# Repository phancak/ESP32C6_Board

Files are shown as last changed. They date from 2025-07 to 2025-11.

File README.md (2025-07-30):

# ESP32-C6 Expansion Board

## Overview

This project features a modular expansion board based on the **ESP32-C6** microcontroller, designed to showcase advanced wireless connectivity and interface flexibility for proof-of-concept embedded systems. The board includes **Wi-Fi 6**, **Bluetooth 5**, and **802.15.4 (Thread/Zigbee)** support, making it suitable for modern IoT applications. In addition to its wireless capabilities, the board exposes key communication interfaces like **QSPI**, **SPI**, **I2C**, and **UART**, enabling it to serve as a powerful, plug-and-play module in larger prototype systems.

## Features

- **ESP32-C6 MCU** – RISC-V single-core processor with Wi-Fi 6, BLE 5, Thread, and Zigbee support
- **QSPI Interface** – For high-speed flash memory or display integration
- **SPI, I2C, UART** – Standard communication protocols for versatile interfacing
- **Low Power Operation** – Ideal for battery-powered and energy-conscious applications
- **Modular Design** – Created for reuse across multiple proof-of-concept hardware projects

## Applications

- **IoT Prototyping** – Wireless communication for smart sensors and devices
- **Home Automation** – Thread/Zigbee-enabled devices with cloud connectivity
- **Industrial Monitoring** – Robust wireless links in noisy environments
- **Education & Research** – Hands-on embedded systems development

## Getting Started

### Hardware Requirements

- ESP32-C6 Expansion Board
- Host MCU or baseboard (if applicable)
- USB-C or serial programmer (if needed)
- 3.3V power supply

### Software Requirements

- [ESP-IDF](https://docs.espressif.com/projects/esp-idf/en/latest/esp32c6/index.html) – Espressif's official development framework
- [esptool.py](https://github.com/espressif/esptool) – Flashing utility
- Serial terminal (e.g., `minicom`, `screen`, or [CoolTerm](https://freeware.the-meiers.org/))

## Setup & Usage

1. **Power the Board** – Supply 3.3V through header or onboard regulator.
2. **Connect to PC** – Use a USB-to-serial adapter if required.
3. **Flash Firmware** – Use `esptool.py` or ESP-IDF to upload your application.
4. **Interface with Peripherals** – Connect SPI/I2C/UART/QSPI devices as needed.
5. **Run Application** – Test wireless or peripheral functionality in your project.

## Schematic

You can view the schematic [here](ESP32C6_Board_Schematics.pdf).

## Future Enhancements

- 🔹 **Thread/Zigbee Demos** – Example apps using 802.15.4 stack
- 🔹 **External Flash/Display Support** – Over QSPI
- 🔹 **Power Optimization Modes** – Advanced sleep and wake-up configurations
- 🔹 **Plug-in Board Compatibility** – For stacking with other expansions

## License

This project is open-source under the **MIT License**.

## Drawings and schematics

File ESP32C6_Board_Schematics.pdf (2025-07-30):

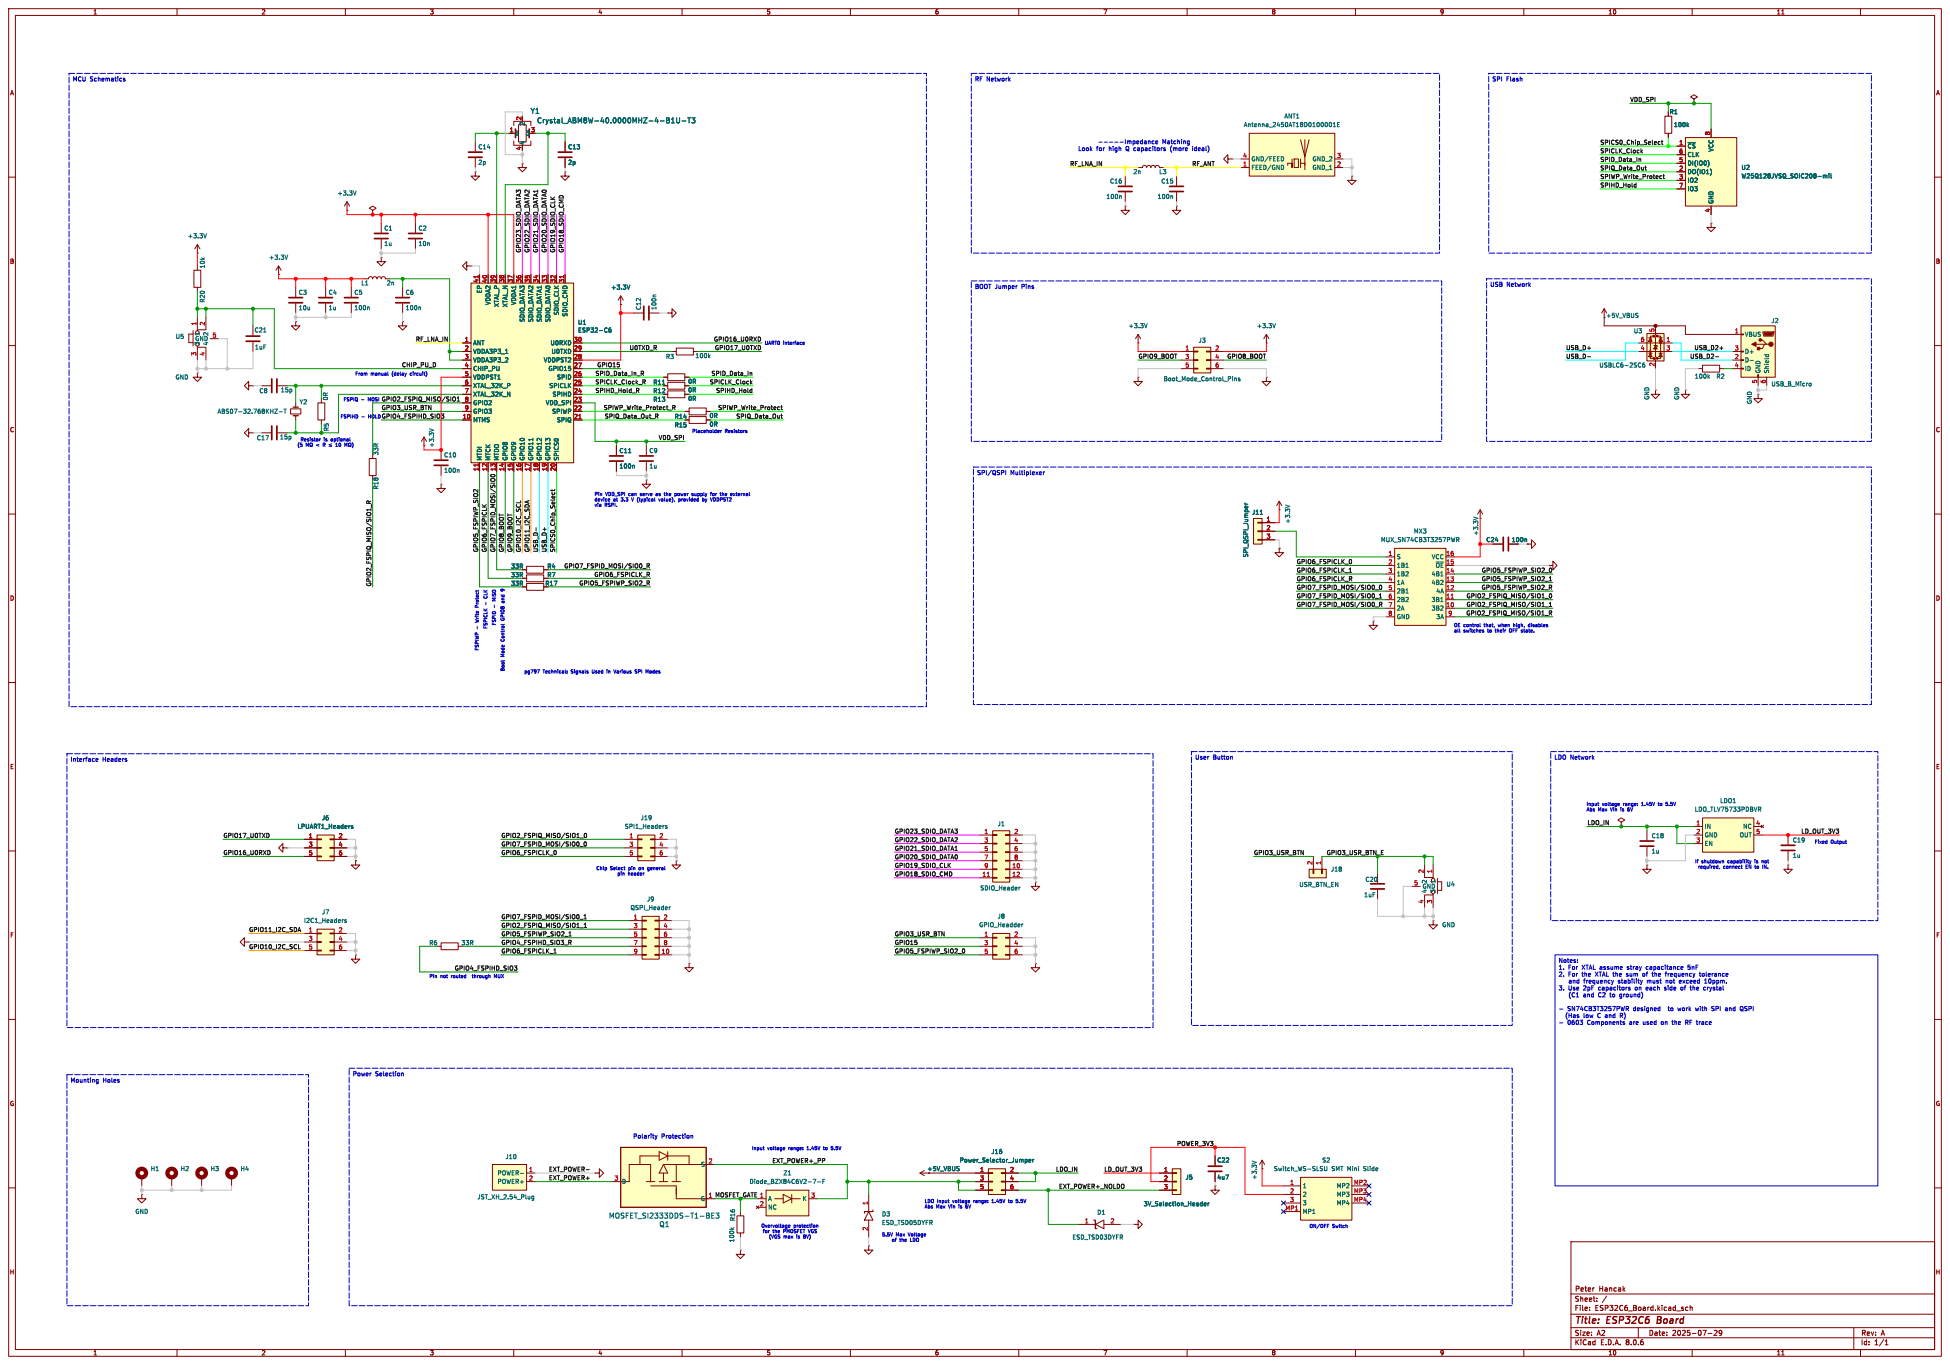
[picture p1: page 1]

Abs Max Vin is 6V

for the PMOSFET VGS
(VGS max is 8V)

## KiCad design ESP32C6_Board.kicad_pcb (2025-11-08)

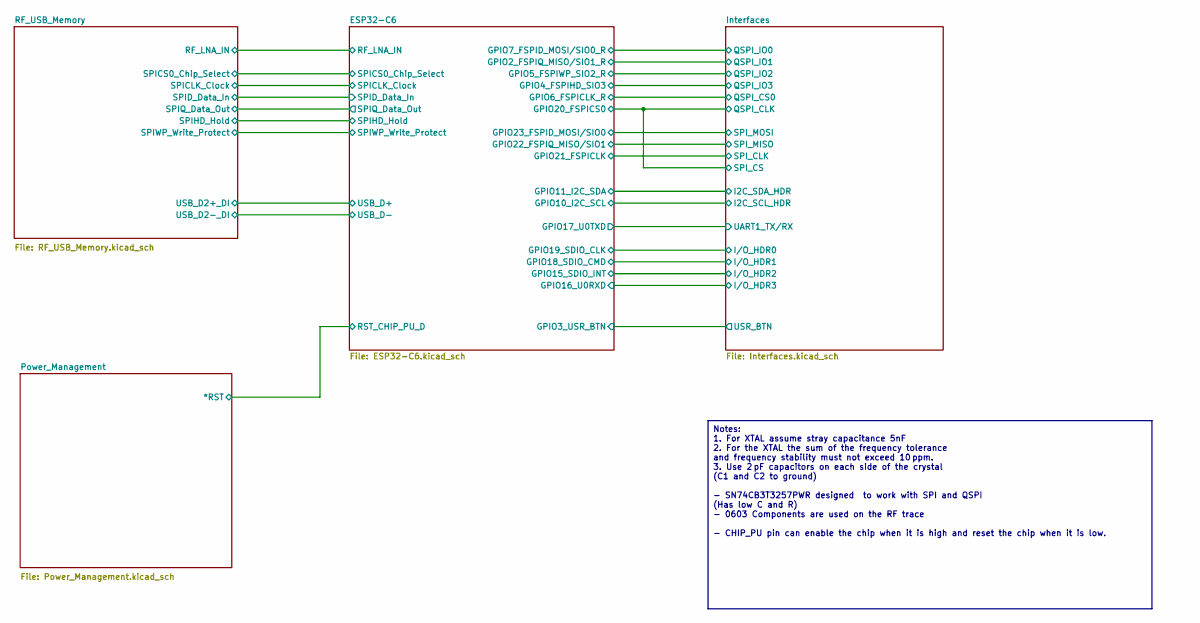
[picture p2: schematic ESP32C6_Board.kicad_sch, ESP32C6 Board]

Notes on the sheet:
Notes: 1. For XTAL assume stray capacitance 5nF 2. For the XTAL the sum of the frequency tolerance and frequency stability must not exceed 10 ppm. 3. Use 2 pF capacitors on each side of the crystal (C1 and C2 to ground) - SN74CB3T3257PWR designed to work with SPI and QSPI (Has low C and R) - 0603 C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

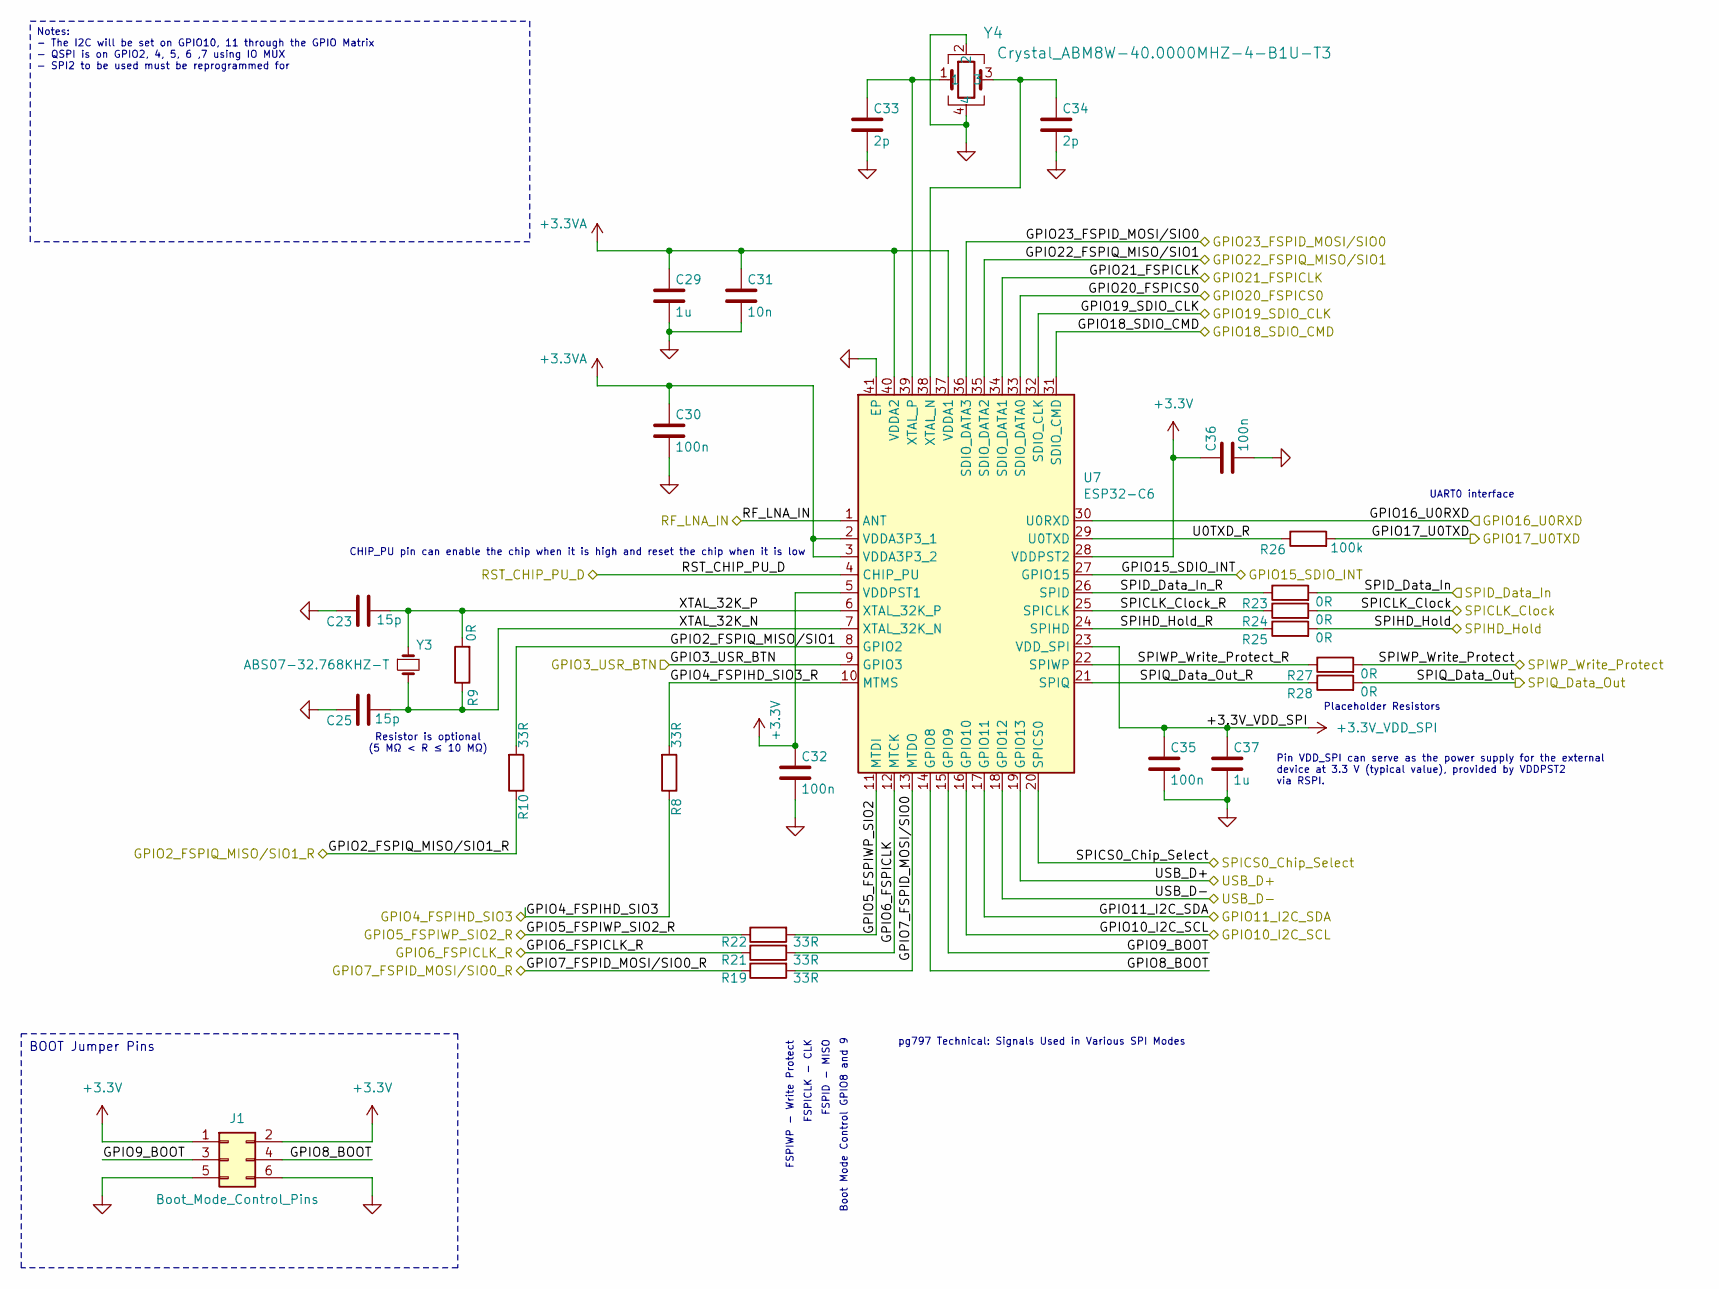
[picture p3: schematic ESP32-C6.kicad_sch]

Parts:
C23, C25: 15p; C_0805_2012Metric
C29, C37: 1u; C_0805_2012Metric
C30, C32, C35, C36: 100n; C_0805_2012Metric
C31: 10n; C_0805_2012Metric
C33, C34: 2p; C_0805_2012Metric
J1: Boot_Mode_Control_Pins; PinHeader_2x03_P2.54mm_Vertical
R8, R10, R19, R21, R22: 33R; R_0805_2012Metric
R9, R23, R24, R25, R27, R28: 0R; R_0805_2012Metric
R26: 100k; R_0805_2012Metric
U7: ESP32-C6; ESP32C6_QFN40P500X500X90-41N-D; Mouser Part Number 356-ESP32-C6
Y3: ABS07-32.768KHZ-T; Crystal_ABS07
Y4: Crystal_ABM8W-40.0000MHZ-4-B1U-T3; CRYSTAL4_ABM10W-40.0000MHZ-8-B1U-T3_ABR

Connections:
+3.3V: C32.1, C36.1, J1.1, J1.2, U7.5 (VDDPST1), U7.28 (VDDPST2); also elsewhere on the board
+3.3VA: C29.1, C30.1, C31.1, U7.2 (VDDA3P3_1), U7.3 (VDDA3P3_2), U7.37 (VDDA1), U7.40 (VDDA2); also elsewhere on the board
+3.3V_VDD_SPI: C35.1, C37.1, U7.23 (VDD_SPI); also elsewhere on the board
/ESP32-C6/GPIO2_FSPIQ_MISO/SIO1: R10.2, U7.8 (GPIO2)
/ESP32-C6/GPIO2_FSPIQ_MISO/SIO1_R: R10.1; also elsewhere on the board
/ESP32-C6/GPIO3_USR_BTN: U7.9 (GPIO3); also elsewhere on the board
/ESP32-C6/GPIO4_FSPIHD_SIO3: R8.1; also elsewhere on the board
/ESP32-C6/GPIO4_FSPIHD_SIO3_R: R8.2, U7.10 (MTMS)
/ESP32-C6/GPIO5_FSPIWP_SIO2: R22.2, U7.11 (MTDI)
/ESP32-C6/GPIO5_FSPIWP_SIO2_R: R22.1; also elsewhere on the board
/ESP32-C6/GPIO6_FSPICLK: R21.2, U7.12 (MTCK)
/ESP32-C6/GPIO6_FSPICLK_R: R21.1; also elsewhere on the board
/ESP32-C6/GPIO7_FSPID_MOSI/SIO0: R19.2, U7.13 (MTDO)
/ESP32-C6/GPIO7_FSPID_MOSI/SIO0_R: R19.1; also elsewhere on the board
/ESP32-C6/GPIO8_BOOT: J1.4, U7.14 (GPIO8)
/ESP32-C6/GPIO9_BOOT: J1.3, U7.15 (GPIO9)
/ESP32-C6/GPIO10_I2C_SCL: U7.16 (GPIO10); also elsewhere on the board
/ESP32-C6/GPIO11_I2C_SDA: U7.17 (GPIO11); also elsewhere on the board
/ESP32-C6/GPIO15_SDIO_INT: U7.27 (GPIO15); also elsewhere on the board
/ESP32-C6/GPIO16_U0RXD: U7.30 (U0RXD); also elsewhere on the board
/ESP32-C6/GPIO17_U0TXD: R26.2; also elsewhere on the board
/ESP32-C6/GPIO18_SDIO_CMD: U7.31 (SDIO_CMD); also elsewhere on the board
/ESP32-C6/GPIO19_SDIO_CLK: U7.32 (SDIO_CLK); also elsewhere on the board
/ESP32-C6/GPIO20_FSPICS0: U7.33 (SDIO_DATA0); also elsewhere on the board
/ESP32-C6/GPIO21_FSPICLK: U7.34 (SDIO_DATA1); also elsewhere on the board
/ESP32-C6/GPIO22_FSPIQ_MISO/SIO1: U7.35 (SDIO_DATA2); also elsewhere on the board
/ESP32-C6/GPIO23_FSPID_MOSI/SIO0: U7.36 (SDIO_DATA3); also elsewhere on the board
/ESP32-C6/RF_LNA_IN: U7.1 (ANT); also elsewhere on the board
/ESP32-C6/RST_CHIP_PU_D: U7.4 (CHIP_PU); also elsewhere on the board
/ESP32-C6/SPICLK_Clock: R24.2; also elsewhere on the board
/ESP32-C6/SPICLK_Clock_R: R24.1, U7.25 (SPICLK)
/ESP32-C6/SPICS0_Chip_Select: U7.20 (SPICS0); also elsewhere on the board
/ESP32-C6/SPID_Data_In: R23.2; also elsewhere on the board
/ESP32-C6/SPID_Data_In_R: R23.1, U7.26 (SPID)
/ESP32-C6/SPIHD_Hold: R25.2; also elsewhere on the board
/ESP32-C6/SPIHD_Hold_R: R25.1, U7.24 (SPIHD)
/ESP32-C6/SPIQ_Data_Out: R28.2; also elsewhere on the board
/ESP32-C6/SPIQ_Data_Out_R: R28.1, U7.21 (SPIQ)
/ESP32-C6/SPIWP_Write_Protect: R27.2; also elsewhere on the board
/ESP32-C6/SPIWP_Write_Protect_R: R27.1, U7.22 (SPIWP)
/ESP32-C6/U0TXD_R: R26.1, U7.29 (U0TXD)
/ESP32-C6/USB_D+: U7.19 (GPIO13); also elsewhere on the board
/ESP32-C6/USB_D-: U7.18 (GPIO12); also elsewhere on the board
/ESP32-C6/XTAL_32K_N: C25.1, R9.1, U7.7 (XTAL_32K_N), Y3.2
/ESP32-C6/XTAL_32K_P: C23.1, R9.2, U7.6 (XTAL_32K_P), Y3.1
GND: C23.2, C25.2, C29.2, C30.2, C31.2, C32.2, C33.2, C34.2, C35.2, C36.2, C37.2, J1.5, J1.6, U7.41 (EP), Y4.2, Y4.4; also elsewhere on the board
unnamed: C34.1, U7.38 (XTAL_N), Y4.3
unnamed: C33.1, U7.39 (XTAL_P), Y4.1

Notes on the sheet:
BOOT Jumper Pins
Notes: - The I2C will be set on GPIO10, 11 through the GPIO Matrix - QSPI is on GPIO2, 4, 5, 6 ,7 using IO MUX - SPI2 to be used must be reprogrammed for
Resistor is optional (5 MΩ < R ≤ 10 MΩ)
FSPIWP - Write Protect
FSPID - MISO
FSPICLK - CLK
UART0 interface
Placeholder Resistors
Boot Mode Control GPIO8 and 9
Pin VDD_SPI can serve as the power supply for the external device at 3.3 V (typical value), provided by VDDPST2 via RSPI.
CHIP_PU pin can enable the chip when it is high and reset the chip when it is low
pg797 Technical: Signals Used in Various SPI Modes

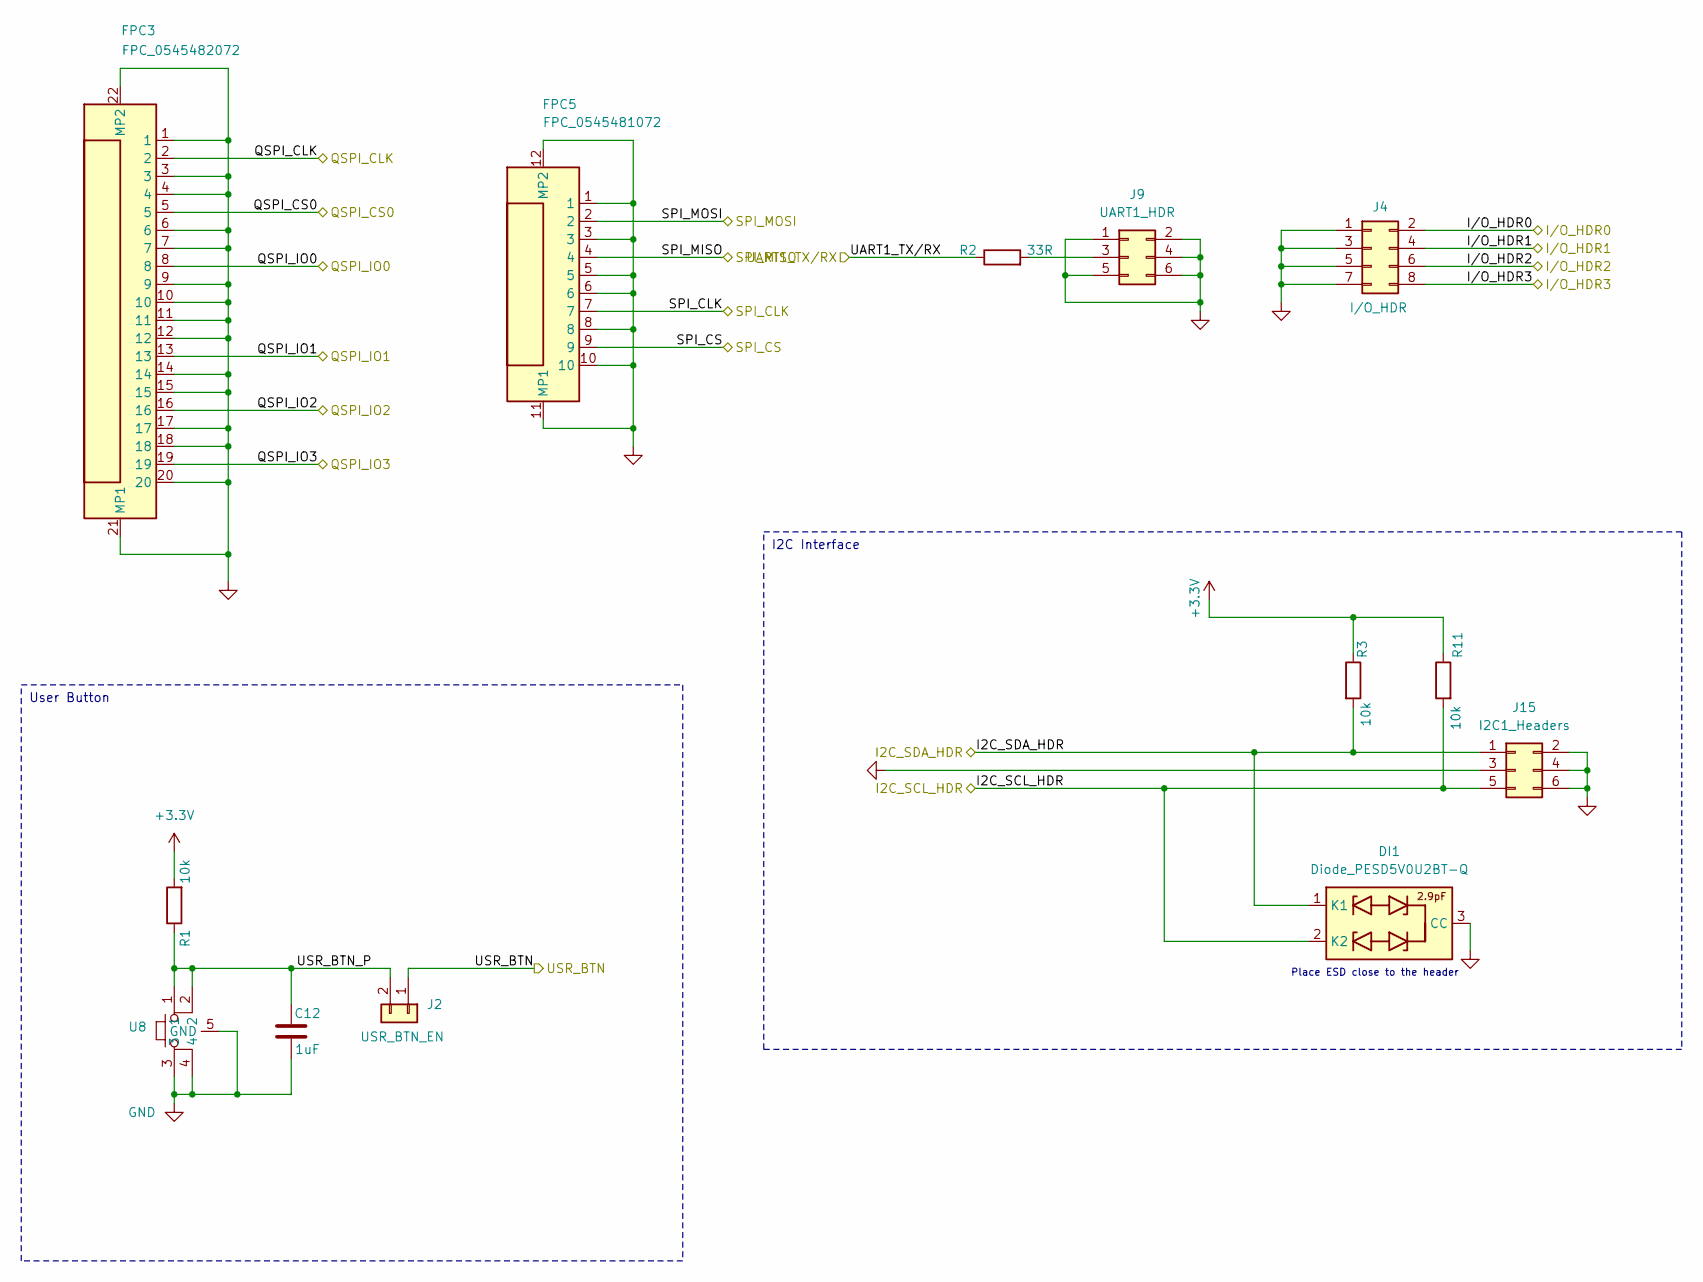
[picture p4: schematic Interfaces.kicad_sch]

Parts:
C12: 1uF; C_0805_2012Metric
DI1: Diode_PESD5V0U2BT-Q; SOT-23; Manufacturer_Part_Number BZX84C6V2-7-F; Mouser Part Number 621-BZX84C6V2-F
FPC3: FPC_0545482072; Manufacturer_Part_Number 0545481072
FPC5: FPC_0545481072; Manufacturer_Part_Number 0545481072
J2: USR_BTN_EN; PinHeader_1x02_P2.54mm_Vertical
J4: I/O_HDR; PinHeader_2x04_P2.54mm_Horizontal
J9: UART1_HDR; PinHeader_2x03_P2.54mm_Horizontal_Court
J15: I2C1_Headers; PinHeader_2x03_P2.54mm_Horizontal_Court
R1, R3, R11: 10k; R_0805_2012Metric
R2: 33R; R_0805_2012Metric
U8: Button_KMR231GLFS

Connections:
+3.3V: R1.2, R3.1, R11.1; also elsewhere on the board
/ESP32-C6/GPIO2_FSPIQ_MISO/SIO1_R: FPC3.13; also elsewhere on the board
/ESP32-C6/GPIO3_USR_BTN: J2.1; also elsewhere on the board
/ESP32-C6/GPIO4_FSPIHD_SIO3: FPC3.19; also elsewhere on the board
/ESP32-C6/GPIO5_FSPIWP_SIO2_R: FPC3.16; also elsewhere on the board
/ESP32-C6/GPIO6_FSPICLK_R: FPC3.5; also elsewhere on the board
/ESP32-C6/GPIO7_FSPID_MOSI/SIO0_R: FPC3.8; also elsewhere on the board
/ESP32-C6/GPIO10_I2C_SCL: DI1.2 (K2), J15.5, R11.2; also elsewhere on the board
/ESP32-C6/GPIO11_I2C_SDA: DI1.1 (K1), J15.1, R3.2; also elsewhere on the board
/ESP32-C6/GPIO15_SDIO_INT: J4.6; also elsewhere on the board
/ESP32-C6/GPIO16_U0RXD: J4.8; also elsewhere on the board
/ESP32-C6/GPIO17_U0TXD: R2.1; also elsewhere on the board
/ESP32-C6/GPIO18_SDIO_CMD: J4.4; also elsewhere on the board
/ESP32-C6/GPIO19_SDIO_CLK: J4.2; also elsewhere on the board
/ESP32-C6/GPIO20_FSPICS0: FPC3.2, FPC5.9; also elsewhere on the board
/ESP32-C6/GPIO21_FSPICLK: FPC5.7; also elsewhere on the board
/ESP32-C6/GPIO22_FSPIQ_MISO/SIO1: FPC5.4; also elsewhere on the board
/ESP32-C6/GPIO23_FSPID_MOSI/SIO0: FPC5.2; also elsewhere on the board
/Interfaces/USR_BTN_P: C12.2, J2.2, R1.1, U8.1, U8.2
GND: C12.1, DI1.3 (CC), FPC3.1, FPC3.3, FPC3.4, FPC3.6, FPC3.7, FPC3.9, FPC3.10, FPC3.11, FPC3.12, FPC3.14, FPC3.15, FPC3.17, FPC3.18, FPC3.20, FPC3.21 (MP1), FPC3.22 (MP2), FPC5.1, FPC5.3, FPC5.5, FPC5.6, FPC5.8, FPC5.10, FPC5.11 (MP1), FPC5.12 (MP2), J4.1, J4.3, J4.5, J4.7, J9.1, J9.2, J9.4, J9.5, J9.6, J15.2, J15.3, J15.4, J15.6, U8.3, U8.4, U8.5 (GND); also elsewhere on the board
unnamed: J9.3, R2.2

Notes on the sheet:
User Button
I2C Interface
Place ESD close to the header

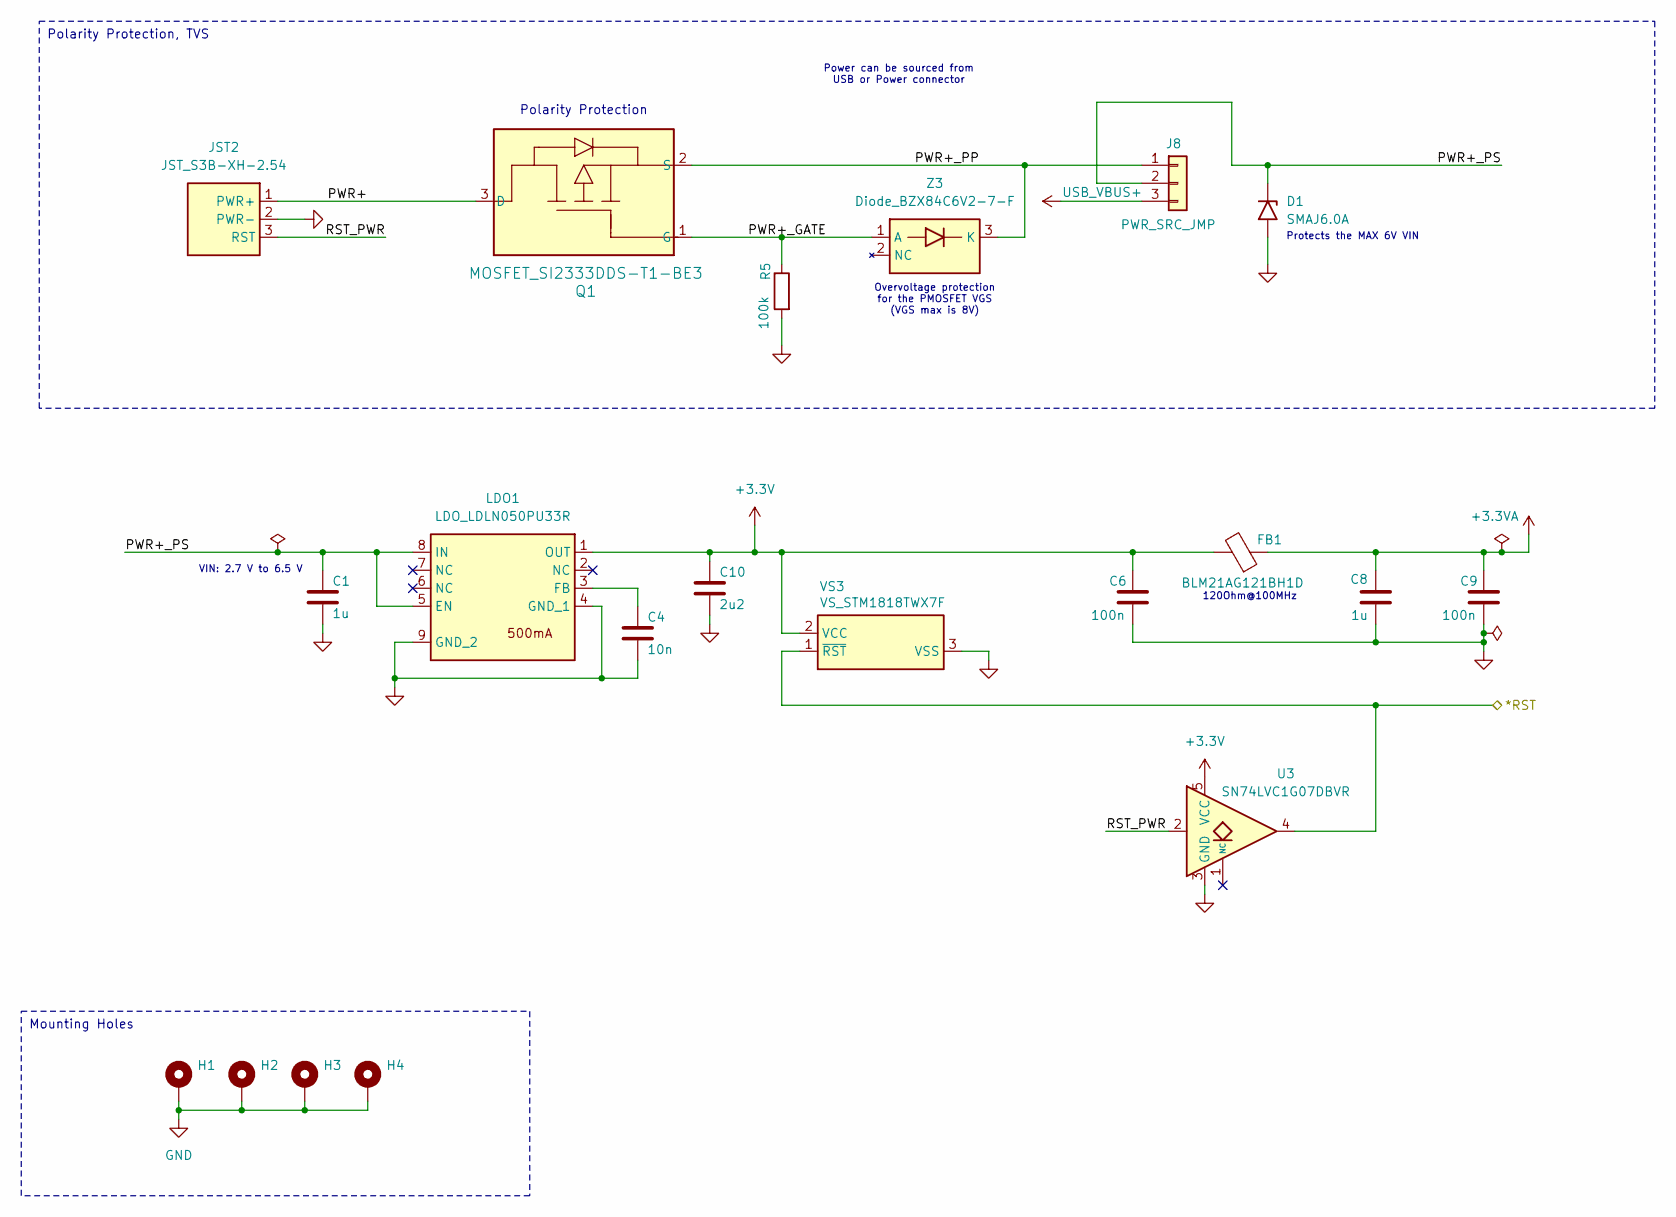
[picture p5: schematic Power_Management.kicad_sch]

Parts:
C1, C8: 1u; C_0805_2012Metric
C4: 10n; C_0805_2012Metric
C6, C9: 100n; C_0805_2012Metric
C10: 2u2; C_0805_2012Metric
D1: SMAJ6.0A; DO-214AC-2
FB1: BLM21AG121BH1D; C_0805_2012Metric
H1, H2, H3, H4: MountingHole_Pad; MountingHole_3.2mm_M3_Pad
J8: PWR_SRC_JMP; PinHeader_1x03_P2.54mm_Vertical
JST2: JST_S3B-XH-2.54; JST_S3B-XH-SHDRRA3W64P0X250_1X3_990X1150X610P; Mouser Part Number 306-S3BXHA1LFSN
LDO1: LDO_LDLN050PU33R; DFN-8-1EP_3x3mm_P0.65mm_EP1.7x2.05mm; Manufacturer_Part_Number LD39200DPUR; Mouser Part Number 511-LD39200DPUR
Q1: MOSFET_SI2333DDS-T1-BE3; MOSFET_ SI2333DDS_SOT_DS-T1-BE3_VIS
R5: 100k; R_0805_2012Metric
U3: SN74LVC1G07DBVR; SOT-23-5
VS3: VS_STM1818TWX7F; SOT-23-3_SOT103P237X112-3N; Mouser Part Number 511-STM1813LWX7F
Z3: Diode_BZX84C6V2-7-F; Diode_BZX84C6V2_SOT96P240X110-3N; Manufacturer_Part_Number BZX84C6V2-7-F; Mouser Part Number 621-BZX84C6V2-F

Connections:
+3.3V: C6.1, C10.1, FB1.2, LDO1.1 (OUT), U3.5 (VCC), VS3.2 (VCC); also elsewhere on the board
+3.3VA: C8.1, C9.1, FB1.1; also elsewhere on the board
/ESP32-C6/RST_CHIP_PU_D: U3.4, VS3.1 (~RST); also elsewhere on the board
/Power_Management/PWR+: JST2.1 (PWR+), Q1.3 (D)
/Power_Management/PWR+_GATE: Q1.1 (G), R5.1, Z3.1 (A)
/Power_Management/PWR+_PP: J8.1, Q1.2 (S), Z3.3 (K)
/Power_Management/PWR+_PS: C1.1, D1.1 (K), J8.2, LDO1.5 (EN), LDO1.8 (IN)
/Power_Management/RST_PWR: JST2.3 (RST), U3.2
GND: C1.2, C4.2, C6.2, C8.2, C9.2, C10.2, D1.2 (A), H1.1, H2.1, H3.1, H4.1, JST2.2 (PWR-), LDO1.4 (GND_1), LDO1.9 (GND_2), R5.2, U3.3 (GND), VS3.3 (VSS); also elsewhere on the board
unnamed: C4.1, LDO1.3 (FB)
USB_VBUS+: J8.3; also elsewhere on the board

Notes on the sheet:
Mounting Holes
Polarity Protection, TVS
Power can be sourced from USB or Power connector
120Ohm@100MHz
VIN: 2.7 V to 6.5 V
Overvoltage protection for the PMOSFET VGS (VGS max is 8V)
Protects the MAX 6V VIN
Polarity Protection

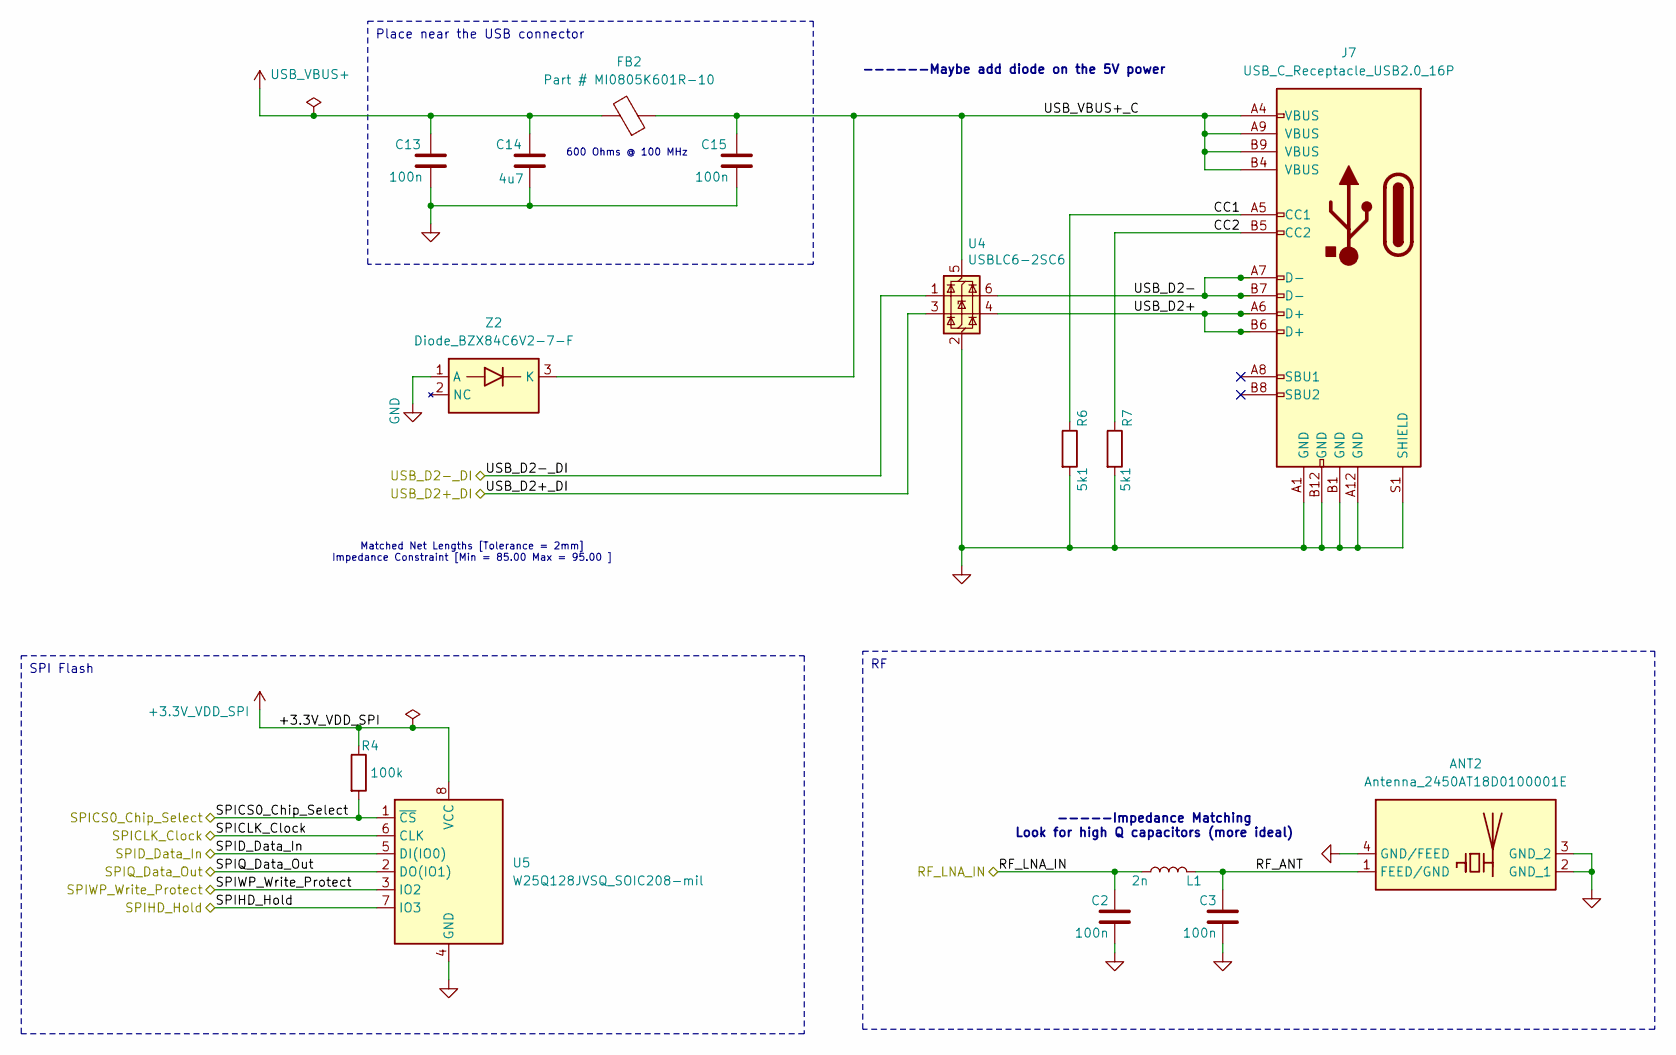
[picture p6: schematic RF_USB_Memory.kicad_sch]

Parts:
ANT2: Antenna_2450AT18D0100001E; Mouser Part Number 609-2450AT18D0100001
C2, C3: 100n; C_0603_1608Metric
C13, C15: 100n; C_0805_2012Metric
C14: 4u7; C_0805_2012Metric
FB2: Part # MI0805K601R-10; C_0805_2012Metric
J7: USB_C_Receptacle_USB2.0_16P; USB_C_Receptacle_HRO_TYPE-C-31-M-12
L1: 2n; L_0603_1608Metric
R4: 100k; R_0805_2012Metric
R6, R7: 5k1; R_0805_2012Metric
U4: USBLC6-2SC6; SOT-23-6
U5: W25Q128JVSQ_SOIC208-mil; SOIC-8_5.23x5.23mm_P1.27mm
Z2: Diode_BZX84C6V2-7-F; Diode_BZX84C6V2_SOT96P240X110-3N; Manufacturer_Part_Number BZX84C6V2-7-F; Mouser Part Number 621-BZX84C6V2-F

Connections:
+3.3V_VDD_SPI: R4.1, U5.8 (VCC); also elsewhere on the board
/ESP32-C6/RF_LNA_IN: C2.1, L1.2; also elsewhere on the board
/ESP32-C6/SPICLK_Clock: U5.6 (CLK); also elsewhere on the board
/ESP32-C6/SPICS0_Chip_Select: R4.2, U5.1 (~CS); also elsewhere on the board
/ESP32-C6/SPID_Data_In: U5.5 (DI(IO0)); also elsewhere on the board
/ESP32-C6/SPIHD_Hold: U5.7 (IO3); also elsewhere on the board
/ESP32-C6/SPIQ_Data_Out: U5.2 (DO(IO1)); also elsewhere on the board
/ESP32-C6/SPIWP_Write_Protect: U5.3 (IO2); also elsewhere on the board
/ESP32-C6/USB_D+: U4.3 (I/O2); also elsewhere on the board
/ESP32-C6/USB_D-: U4.1 (I/O1); also elsewhere on the board
/RF_USB_Memory/CC1: J7.A5 (CC1), R6.1
/RF_USB_Memory/CC2: J7.B5 (CC2), R7.1
/RF_USB_Memory/RF_ANT: ANT2.1 (FEED/GND), C3.1, L1.1
/RF_USB_Memory/USB_D2+: J7.A6 (D+), J7.B6 (D+), U4.4 (I/O2)
/RF_USB_Memory/USB_D2-: J7.A7 (D-), J7.B7 (D-), U4.6 (I/O1)
/RF_USB_Memory/USB_VBUS+_C: C15.1, FB2.1, J7.A4 (VBUS), J7.A9 (VBUS), J7.B4 (VBUS), J7.B9 (VBUS), U4.5 (VBUS), Z2.3 (K)
GND: ANT2.2 (GND_1), ANT2.3 (GND_2), ANT2.4 (GND/FEED), C2.2, C3.2, C13.2, C14.2, C15.2, J7.A1 (GND), J7.A12 (GND), J7.B1 (GND), J7.B12 (GND), J7.S1 (SHIELD), R6.2, R7.2, U4.2 (GND), U5.4 (GND), Z2.1 (A); also elsewhere on the board
USB_VBUS+: C13.1, C14.1, FB2.2; also elsewhere on the board

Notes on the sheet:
SPI Flash
Place near the USB connector
Matched Net Lengths [Tolerance = 2mm] Impedance Constraint [Min = 85.00 Max = 95.00 ]
-----Impedance Matching Look for high Q capacitors (more ideal)
------Maybe add diode on the 5V power
600 Ohms @ 100 MHz

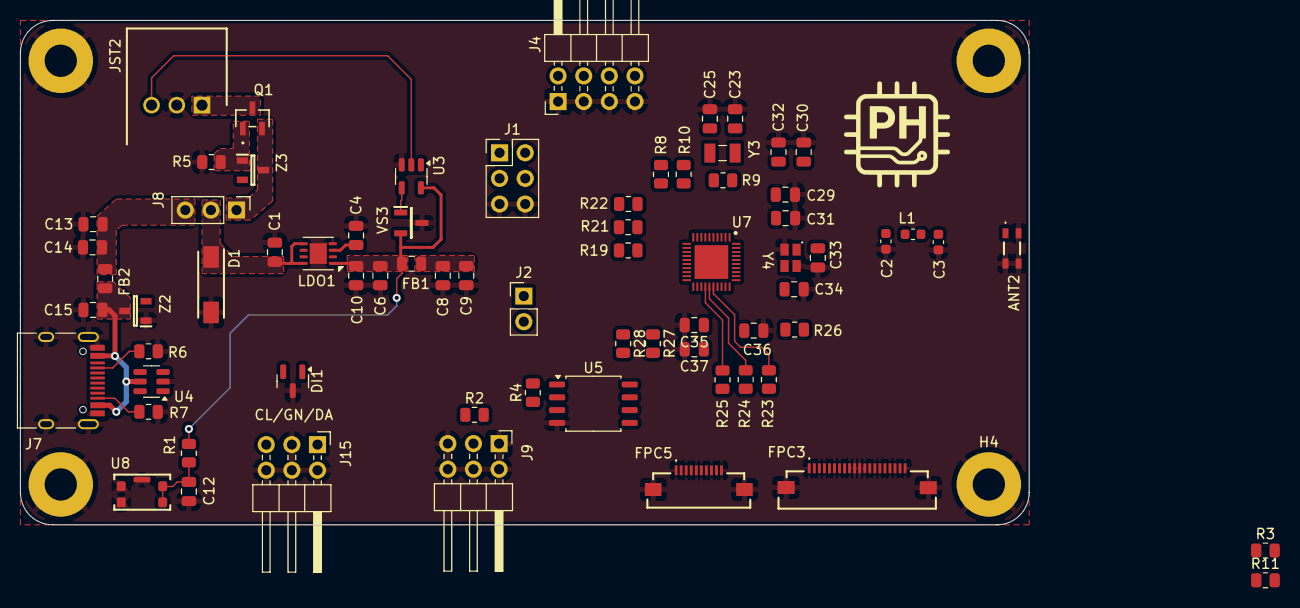
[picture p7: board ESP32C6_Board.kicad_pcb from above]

Board: 4 copper layers, 100.0 x 50.0 mm, 75 parts (0 on the bottom side), 63 nets.
